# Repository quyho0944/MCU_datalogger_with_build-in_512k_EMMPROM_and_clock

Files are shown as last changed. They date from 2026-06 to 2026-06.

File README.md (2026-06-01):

# MCU Datalogger with Built-in 512k EEPROM & RTC Clock

## 📝 Giới thiệu dự án
Dự án thiết kế phần cứng **MCU Datalogger** được thực hiện trên nền tảng **KiCad**. Hệ thống được tối ưu hóa cho các ứng dụng thu thập, giám sát và lưu trữ dữ liệu từ cảm biến hoặc các thiết bị công nghiệp theo thời gian thực (Real-time Data Logging). 

Bo mạch được thiết kế nhỏ gọn, độ nhiễu thấp, sẵn sàng cho các ứng dụng thực tế đòi hỏi độ tin cậy cao trong việc lưu trữ dữ liệu dài hạn.

---

## 🚀 Tính năng nổi bật
* **Bộ nhớ lưu trữ dung lượng lớn:** Tích hợp chip nhớ ngoại vi **EEPROM 512k**, cho phép lưu trữ hàng ngàn bản ghi dữ liệu một cách an toàn. Dữ liệu không bị mất khi hệ thống mất nguồn điện đột ngột (Non-volatile memory).
* **Thời gian thực chính xác:** Tích hợp mạch đồng hồ thời gian thực (**RTC Clock**), tự động gắn nhãn thời gian (Timestamp: Ngày/Tháng/Năm/Giờ/Phút/Giây) chính xác cho từng gói dữ liệu thu thập được.
* **Thiết kế phần cứng chuyên nghiệp:** Sơ đồ nguyên lý (Schematic) và thiết kế mạch in (PCB Layout) được tối ưu hóa hoàn toàn trên phần mềm **KiCad**.

---

## 🛠️ Thành phần linh kiện chính
* **MCU:** ATmega328P-AU
* **Storage:** EEPROM 512k (Giao tiếp I2C)
* **Clock:** RTC Module DS1337S+
* **Nguồn cấp:** Tích hợp mạch bảo vệ và hạ áp ổn định.

---

## 📂 Cấu trúc thư mục dự án
```text
├── Hardware/          # Chứa file thiết kế KiCad (Schematic, PCB, 3D Model)
├── Firmware/          # Mã nguồn chương trình cho MCU (nếu có)
├── Docs/              # Tài liệu kỹ thuật, Datasheet linh kiện
└── README.md          # File giới thiệu dự án

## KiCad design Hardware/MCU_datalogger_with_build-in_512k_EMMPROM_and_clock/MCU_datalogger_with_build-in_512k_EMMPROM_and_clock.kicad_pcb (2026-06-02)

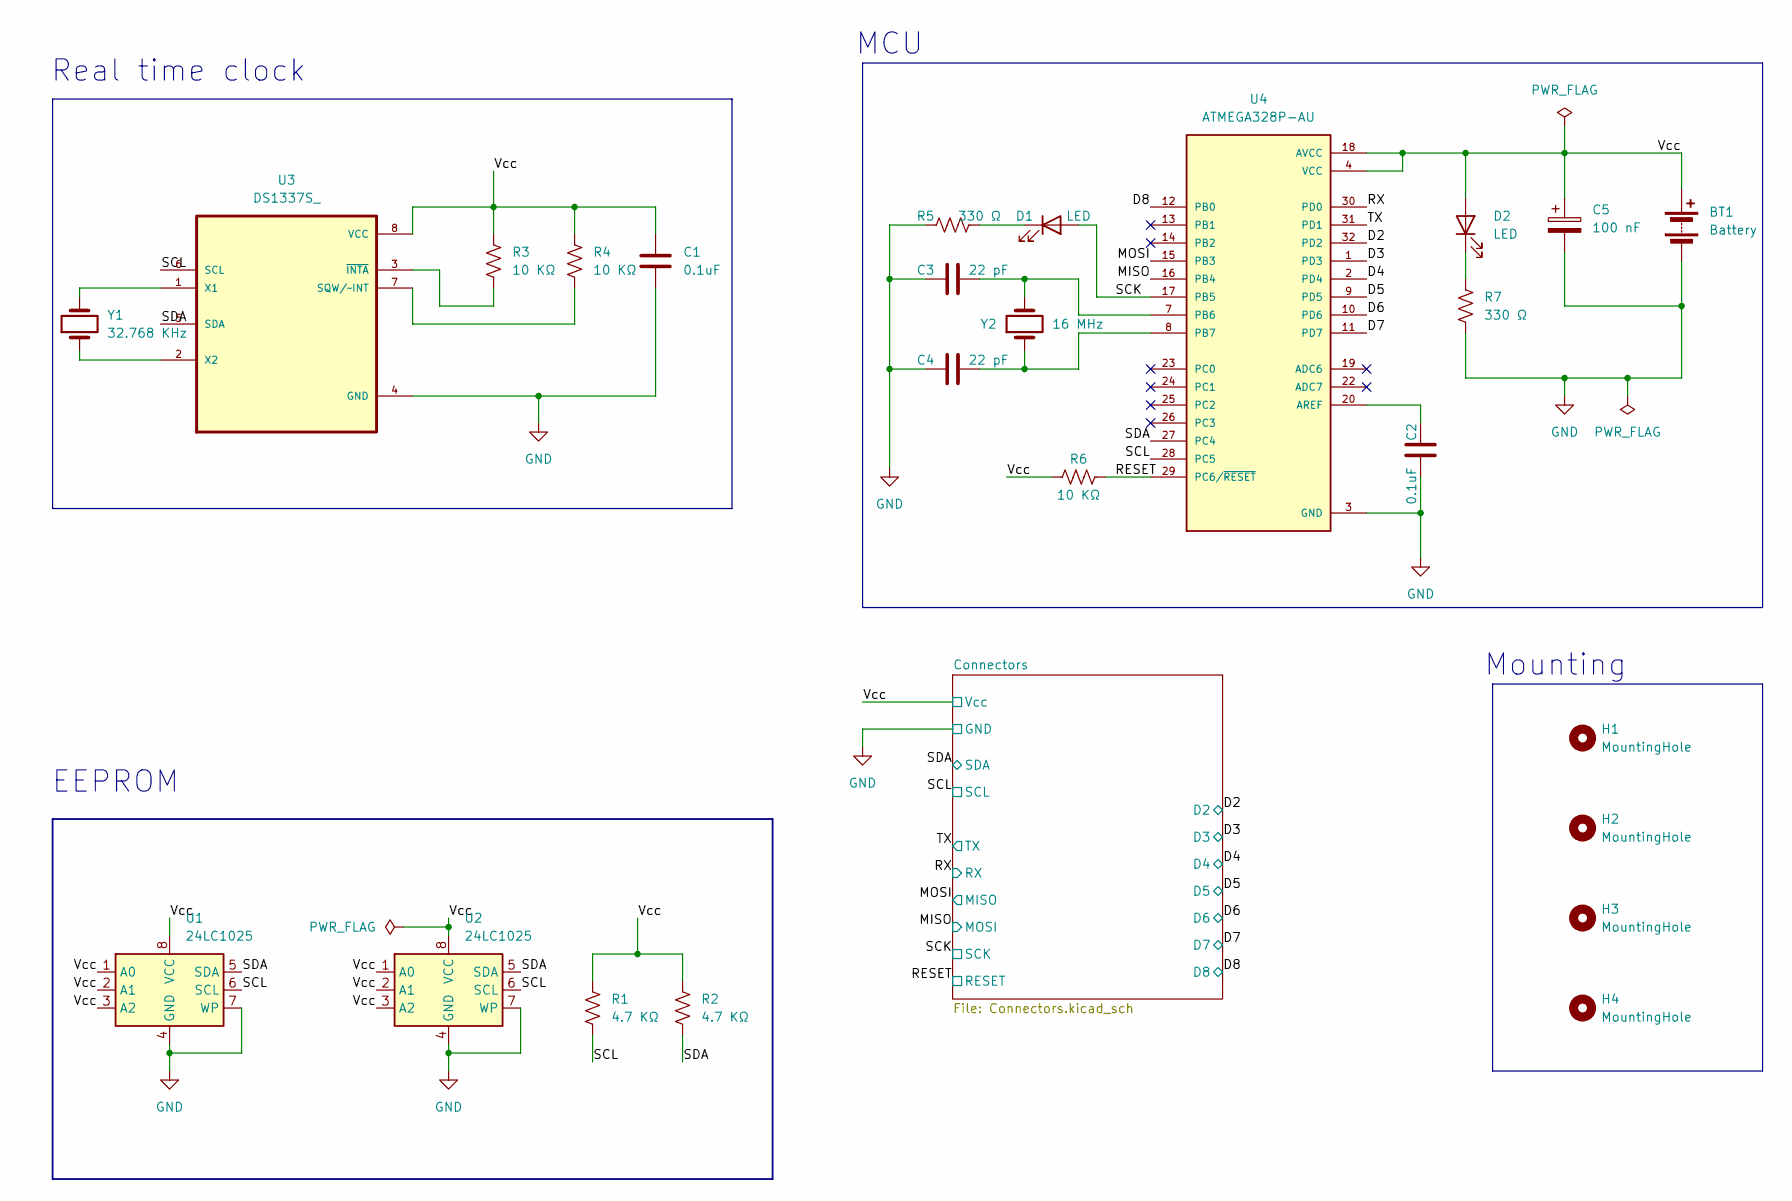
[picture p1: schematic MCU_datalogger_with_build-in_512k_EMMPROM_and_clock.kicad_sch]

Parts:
BT1: Battery; PinHeader_1x02_P2.54mm_Vertical
C1, C2: 0.1uF; C_0805_2012Metric
C3, C4: 22 pF; C_0805_2012Metric
C5: 100 nF; C_0805_2012Metric
D1, D2: LED; LED_0805_2012Metric
H1, H2, H3, H4: MountingHole; MountingHole_2.1mm
R1, R2: 4.7 KΩ; R_0805_2012Metric
R3, R4, R6: 10 KΩ; R_0805_2012Metric
R5, R7: 330 Ω; R_0805_2012Metric
U1, U2: 24LC1025; SOIC-8_5.3x5.3mm_P1.27mm
U3: DS1337S_; SOIC127P600X175-8N
U4: ATMEGA328P-AU; QFP80P900X900X120-32N; PARTREV 8271A
Y1: 32.768 KHz; Crystal_SMD_5032-2Pin_5.0x3.2mm_HandSoldering
Y2: 16 MHz; Crystal_SMD_5032-2Pin_5.0x3.2mm_HandSoldering

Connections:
/D2: U4.32 (PD2); also elsewhere on the board
/D3: U4.1 (PD3); also elsewhere on the board
/D4: U4.2 (PD4); also elsewhere on the board
/D5: U4.9 (PD5); also elsewhere on the board
/D6: U4.10 (PD6); also elsewhere on the board
/D7: U4.11 (PD7); also elsewhere on the board
/D8: U4.12 (PB0); also elsewhere on the board
/MISO: U4.16 (PB4); also elsewhere on the board
/MOSI: U4.15 (PB3); also elsewhere on the board
/RESET: R6.2, U4.29 (PC6/~RESET); also elsewhere on the board
/RX: U4.30 (PD0); also elsewhere on the board
/SCK: D1.2 (A), U4.17 (PB5); also elsewhere on the board
/SCL: R1.2, U1.6 (SCL), U2.6 (SCL), U3.6 (SCL), U4.28 (PC5); also elsewhere on the board
/SDA: R2.2, U1.5 (SDA), U2.5 (SDA), U3.5 (SDA), U4.27 (PC4); also elsewhere on the board
/TX: U4.31 (PD1); also elsewhere on the board
GND: BT1.2 (-), C1.2, C2.2, C3.1, C4.1, C5.2, R5.1, R7.1, U1.4 (GND), U1.7 (WP), U2.4 (GND), U2.7 (WP), U3.4 (GND), U4.3 (GND), U4.5 (GND), U4.21 (GND); also elsewhere on the board
unnamed: D1.1 (K), R5.2
unnamed: D2.1 (K), R7.2
unnamed: R4.2, U3.7 (SQW/~INT)
unnamed: U3.1 (X1), Y1.2
unnamed: U3.2 (X2), Y1.1
unnamed: R3.2, U3.3 (~INTA)
unnamed: C2.1, U4.20 (AREF)
unnamed: C3.2, U4.7 (PB6), Y2.2
unnamed: C4.2, U4.8 (PB7), Y2.1
VCC: BT1.1 (+), C1.1, C5.1, D2.2 (A), R1.1, R2.1, R3.1, R4.1, R6.1, U1.1 (A0), U1.2 (A1), U1.3 (A2), U1.8 (VCC), U2.1 (A0), U2.2 (A1), U2.3 (A2), U2.8 (VCC), U3.8 (VCC), U4.4 (VCC), U4.6 (VCC), U4.18 (AVCC); also elsewhere on the board

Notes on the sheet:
Mounting
MCU
EEPROM
Real time clock

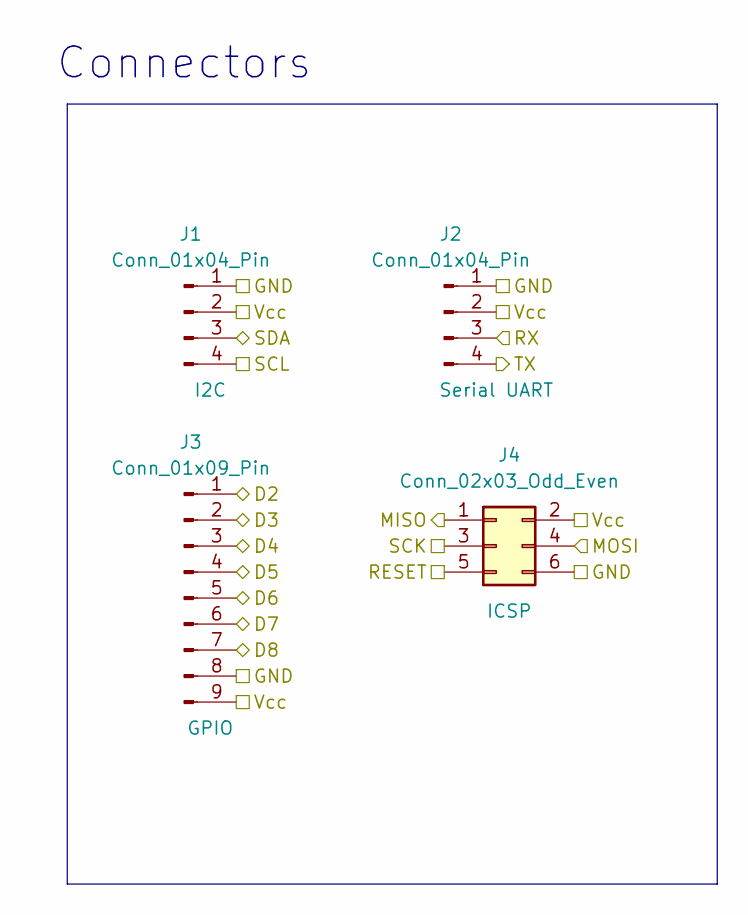
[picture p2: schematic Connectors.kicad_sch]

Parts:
J1, J2: Conn_01x04_Pin; PinHeader_1x04_P2.54mm_Vertical
J3: Conn_01x09_Pin; PinHeader_1x09_P2.54mm_Vertical
J4: Conn_02x03_Odd_Even; PinHeader_2x03_P2.54mm_Vertical

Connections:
/D2: J3.1; also elsewhere on the board
/D3: J3.2; also elsewhere on the board
/D4: J3.3; also elsewhere on the board
/D5: J3.4; also elsewhere on the board
/D6: J3.5; also elsewhere on the board
/D7: J3.6; also elsewhere on the board
/D8: J3.7; also elsewhere on the board
/MISO: J4.4; also elsewhere on the board
/MOSI: J4.1; also elsewhere on the board
/RESET: J4.5; also elsewhere on the board
/RX: J2.3; also elsewhere on the board
/SCK: J4.3; also elsewhere on the board
/SCL: J1.4; also elsewhere on the board
/SDA: J1.3; also elsewhere on the board
/TX: J2.4; also elsewhere on the board
GND: J1.1, J2.1, J3.8, J4.6; also elsewhere on the board
VCC: J1.2, J2.2, J3.9, J4.2; also elsewhere on the board

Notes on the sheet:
Connectors

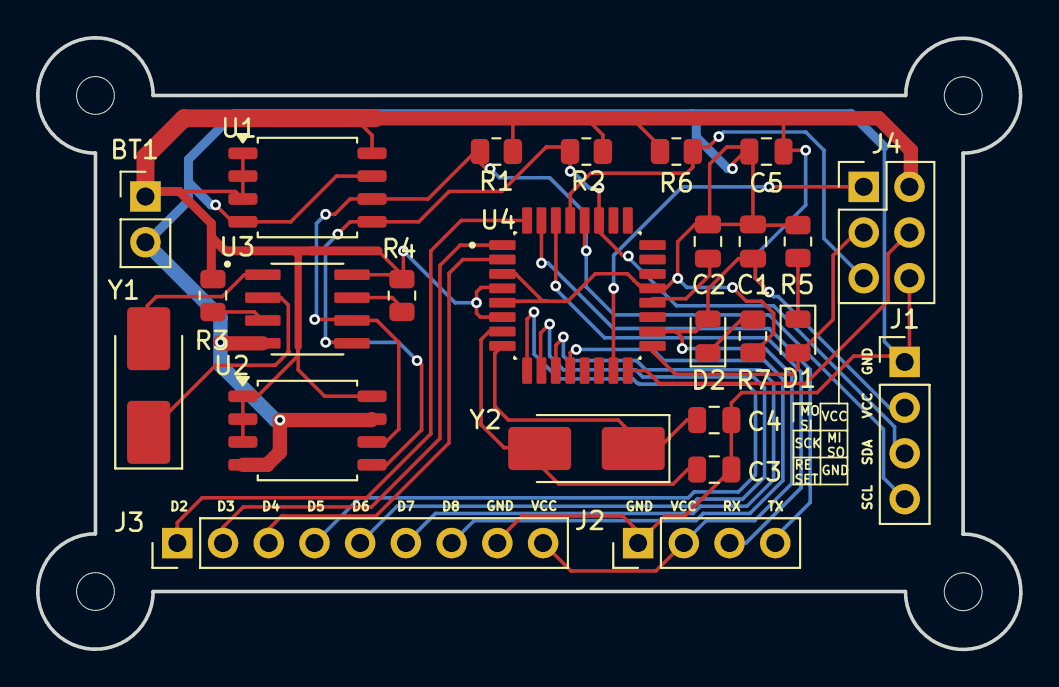
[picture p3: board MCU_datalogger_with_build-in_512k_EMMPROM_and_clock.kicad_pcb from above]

Board: 2 copper layers, 54.6 x 34.0 mm, 29 parts (0 on the bottom side), 26 nets.
